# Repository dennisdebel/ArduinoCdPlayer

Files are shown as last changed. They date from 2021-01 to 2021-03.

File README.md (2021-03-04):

# Arduino CD player

Using an Arduino Pro-mini and an IDE CD-ROM drive to create a standalone CD player.
Based on the [ATAPIDUINO](http://singlevalve.web.fc2.com/Atapiduino/atapiduino.htm) project - code for this in the `original` folder.

For more details, see project on [hackaday.io](https://hackaday.io/project/176545-arduino-cd-player).

# To do
* Add opamp buffer after DAC to protect the output (from accidental plugging in other outputs).

# Supported IDE CD-ROM drives
Sources from [ATAPIDUINO](http://singlevalve.web.fc2.com/Atapiduino/atapiduino.htm) and [ArduinoCdPlayer](https://hackaday.io/project/176545-arduino-cd-player) and [here](https://hackaday.io/project/24905-using-old-cd-drive-as-a-music-player):

## Testing
* AOpen CRW5224 (2003)

## Compatible drives
* AZTECH CDA66801I (1995)
* BTC F563E (2001)
* CREATIVE CD5233E (?) (Starts PLAY instead of remaining paused when NEXT/PREV is used on stopped unit)
* HITACHI CDR-8130 (1997)
* HITACHI CDR-8230 (1997)
* LG CRD-8320B (1998)
* LG CRD-8322B (1999)
* LG CRD-8521B (2001)
* LG GCE-8527B (2005)
* LITE-ON LTN-403L (2000)
* LITE-ON LTN486S (2001)
* NEC CDR 1800A (1997)
* NEC DV-5800A (2001) ("DVD-ROM READER")
* SAMSUNG SC-148C (2001)
* SONY CDU5211 (2001)
* TEAC CD-532E (2000)
* TEAC CD-540E (2001)
* Ultima Electronics CHA-50 (????)

## Non Compatible or possible defect Units
* Compaq CRC#D-8241B (1998) (erratic, defect?)
* Compaq CR-588 (1998) (erratic, defect?)
* H.L Datastorage GCR-8481B (2002) (fails init proc.)
* LG DVD-ROM Drive GDR-H30N (2007) (fails init proc.)
* Philips DVDROM DROM6116/34 (2004) (Only reads TOC sometimes)
* Toshiba XM-6402B (1999) (fails init proc.)

# References
* https://hackaday.io/project/176545-arduino-cd-player
* https://hackaday.io/project/24905-using-old-cd-drive-as-a-music-player
* http://singlevalve.web.fc2.com/Atapiduino/atapiduino.htm 
* https://github.com/lmiori92/AtapiduinoSingleChip
* productized version of similar idea: [CD-ROM DVD-ROM IDE ROM Audio Player controller DIY kit ROM to Turntable](https://www.ebay.co.uk/itm/CD-ROM-DVD-ROM-IDE-ROM-Audio-Player-controller-DIY-kit-ROM-to-Turntable/324207457799)

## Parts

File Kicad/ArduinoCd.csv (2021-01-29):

Id | Designator | Package | Quantity | Designation | Supplier and ref
1 | REF**,REF**,REF**,REF** | MountingHole_3.2mm_M3 | 4 | MountingHole_3.2mm_M3
2 | U1,U2 | TSSOP-24_4.4x7.8mm_P0.65mm | 2 | PCA9555PW
3 | A1 | Arduino_ProMini | 1 | Arduino_ProMini
4 | C1,C2,C5,C7,C10,C12,C13,C15,C19,C21,C22,C25,C26 | C_0805_2012Metric_Pad1.15x1.40mm_HandSolder | 13 | 0.1uF
5 | C3,C4 | C_0805_2012Metric_Pad1.15x1.40mm_HandSolder | 2 | 15pF
6 | C6,C8,C18 | C_0805_2012Metric_Pad1.15x1.40mm_HandSolder | 3 | 4.7uF
7 | C9,C11,C14,C24 | C_0805_2012Metric_Pad1.15x1.40mm_HandSolder | 4 | 10uF
8 | C16,C17 | C_0805_2012Metric_Pad1.15x1.40mm_HandSolder | 2 | 2.2uF
9 | C20,C23 | C_0805_2012Metric_Pad1.15x1.40mm_HandSolder | 2 | 2.2nF
10 | D1 | LED_D3.0mm | 1 | LED
11 | D2 | D_SMB_Handsoldering | 1 | D_Small
12 | J1,J3,J5,J6,J11,J12,J13,J14 | PinHeader_1x02_P2.54mm_Vertical | 8 | Conn_01x02
13 | J2 | PinHeader_1x02_P2.54mm_Vertical | 1 | A4-A5
14 | J4 | FCR684204T | 1 | fcr684204t
15 | J7 | PinHeader_1x03_P2.54mm_Vertical | 1 | IR SENSE
16 | J8 | PinHeader_1x02_P2.54mm_Vertical | 1 | S/PDIF-IN0
17 | J9 | PinHeader_1x02_P2.54mm_Vertical | 1 | S/PDIF-IN1
18 | J10 | PinHeader_1x04_P2.54mm_Vertical | 1 | OLED
19 | J15 | PinHeader_2x20_P2.54mm_Vertical | 1 | IDE
20 | J16 | PinHeader_1x02_P2.54mm_Vertical | 1 | 12v-IN
21 | J17 | PinHeader_1x04_P2.54mm_Vertical | 1 | LineOut
22 | Q1,Q2,Q3,Q4 | SOT-23_Handsoldering | 4 | 2N7002
23 | R1 | R_0805_2012Metric_Pad1.15x1.40mm_HandSolder | 1 | 2k
24 | R2,R5,R6,R7,R8,R9,R10,R11,R12,R13,R14,R15,R16 | R_0805_2012Metric_Pad1.15x1.40mm_HandSolder | 13 | 10k
25 | R3,R4 | R_0805_2012Metric_Pad1.15x1.40mm_HandSolder | 2 | 75R
26 | R17 | R_0805_2012Metric_Pad1.15x1.40mm_HandSolder | 1 | 200k
27 | R18,R19,R20,R21,R22 | R_0805_2012Metric_Pad1.15x1.40mm_HandSolder | 5 | 100R
28 | R23 | R_0805_2012Metric_Pad1.15x1.40mm_HandSolder | 1 | 33.2k
29 | R24 | R_0805_2012Metric_Pad1.15x1.40mm_HandSolder | 1 | 499R
30 | R25 | R_0805_2012Metric_Pad1.15x1.40mm_HandSolder | 1 | 7.25k
31 | R26,R27 | R_0805_2012Metric_Pad1.15x1.40mm_HandSolder | 2 | 470R
32 | R28 | R_0805_2012Metric_Pad1.15x1.40mm_HandSolder | 1 | 49.9k
33 | R29 | R_0805_2012Metric_Pad1.15x1.40mm_HandSolder | 1 | 2.75k
34 | R30 | R_0805_2012Metric_Pad1.15x1.40mm_HandSolder | 1 | 453k
35 | SW1 | SW_SPST_B3S-1000 | 1 | Stop
36 | SW2 | SW_SPST_B3S-1000 | 1 | Play
37 | SW3 | SW_SPST_B3S-1000 | 1 | Pause
38 | SW4 | SW_SPST_B3S-1000 | 1 | PrevTrack
39 | SW5 | SW_SPST_B3S-1000 | 1 | NextTrack
40 | SW6 | SW_SPST_B3S-1000 | 1 | FastForward
41 | SW7 | SW_SPST_B3S-1000 | 1 | Rewind
42 | SW8 | SW_SPST_B3S-1000 | 1 | Eject
43 | TP1 | TestPoint_Pad_1.0x1.0mm | 1 | 3v3
44 | TP2 | TestPoint_Pad_1.0x1.0mm | 1 | MUTE
45 | TP3 | TestPoint_Pad_1.0x1.0mm | 1 | AVDD
46 | TP4 | TestPoint_Pad_1.0x1.0mm | 1 | 5v
47 | U3 | SSOP-28_5.3x10.2mm_P0.65mm | 1 | WM8805
48 | U4 | SOT-223-3_TabPin2 | 1 | AMS1117-3.3
49 | U5 | TSSOP-20_4.4x6.5mm_P0.65mm | 1 | PCM5102
50 | U6 | MSOP-10_3x3mm_P0.5mm | 1 | LT3042
51 | U7 | SOT-223-3_TabPin2 | 1 | AMS1117-5.0
52 | Y1 | Crystal_SMD_HC49-SD | 1 | 12MHz

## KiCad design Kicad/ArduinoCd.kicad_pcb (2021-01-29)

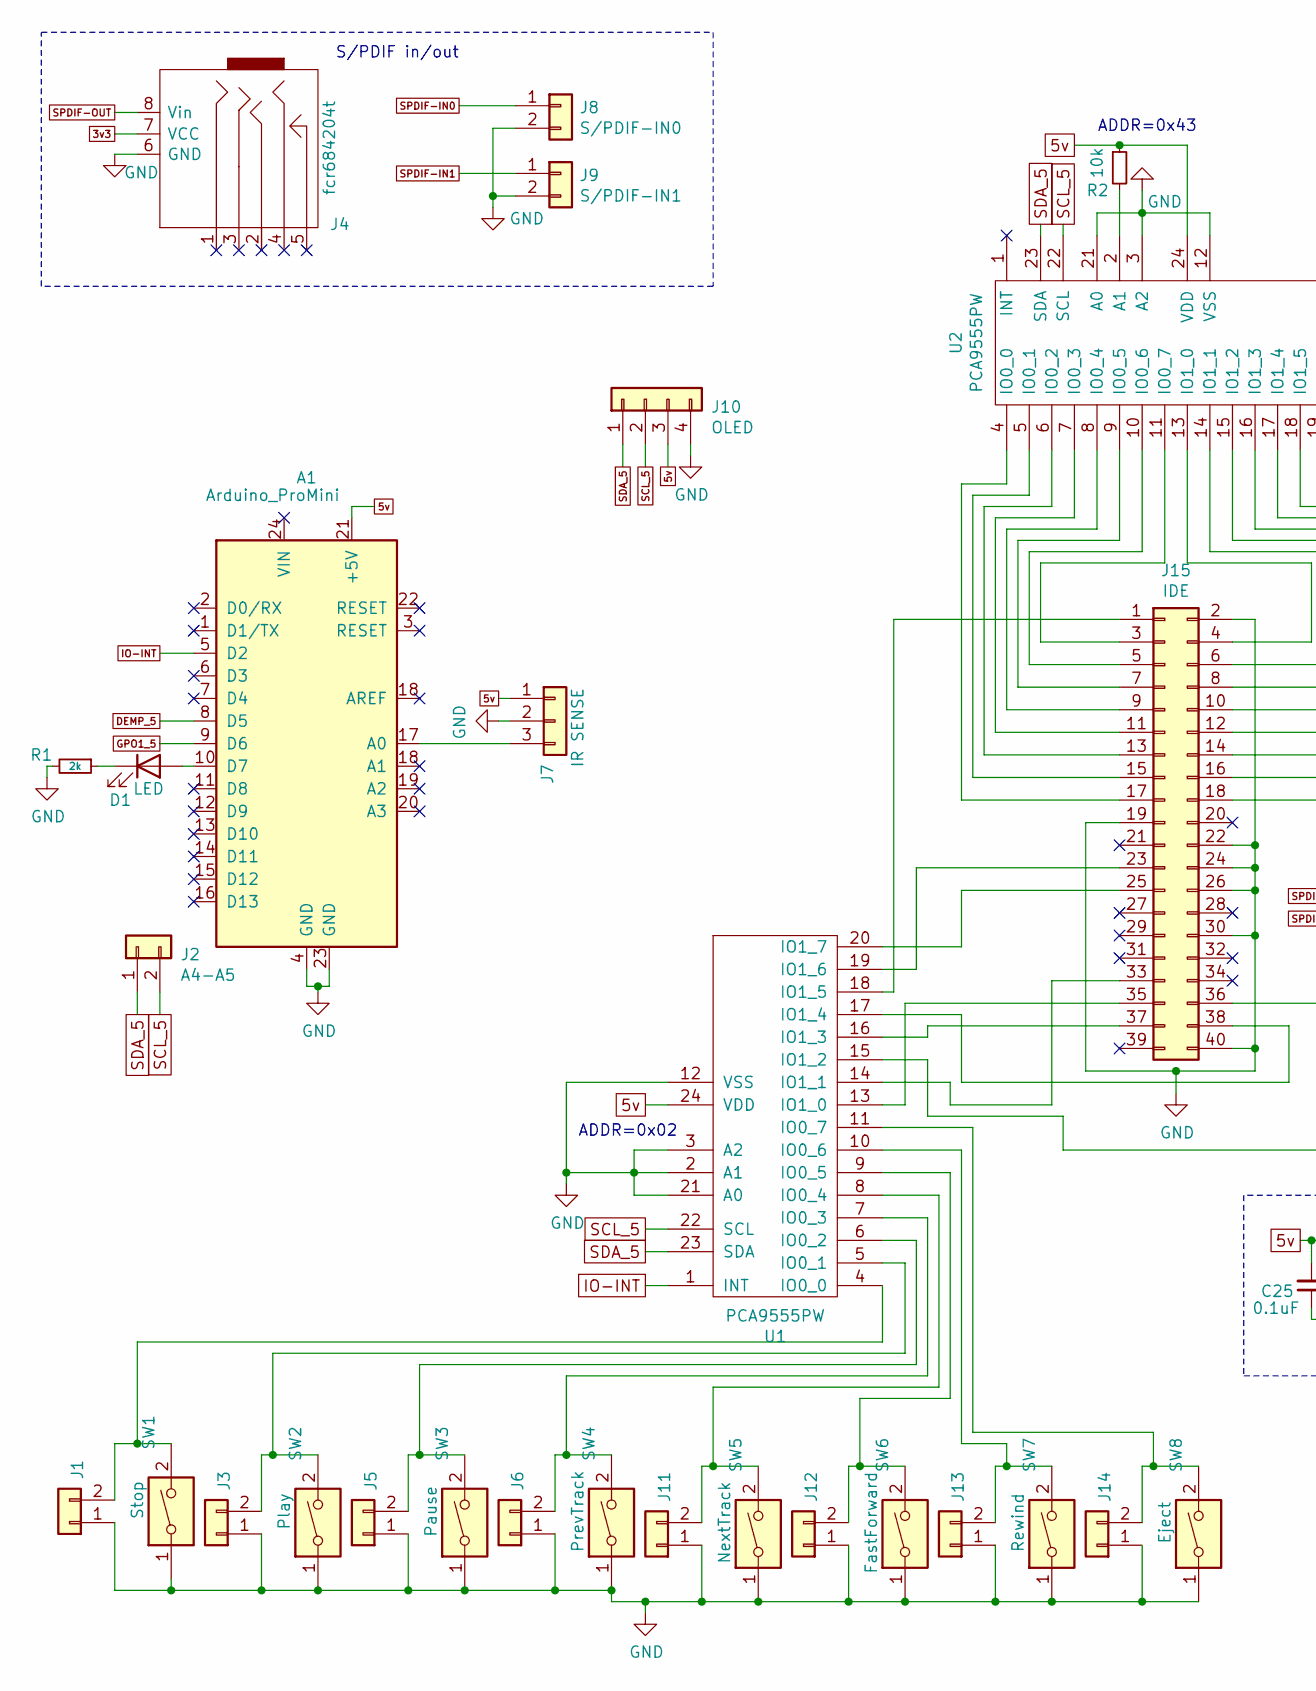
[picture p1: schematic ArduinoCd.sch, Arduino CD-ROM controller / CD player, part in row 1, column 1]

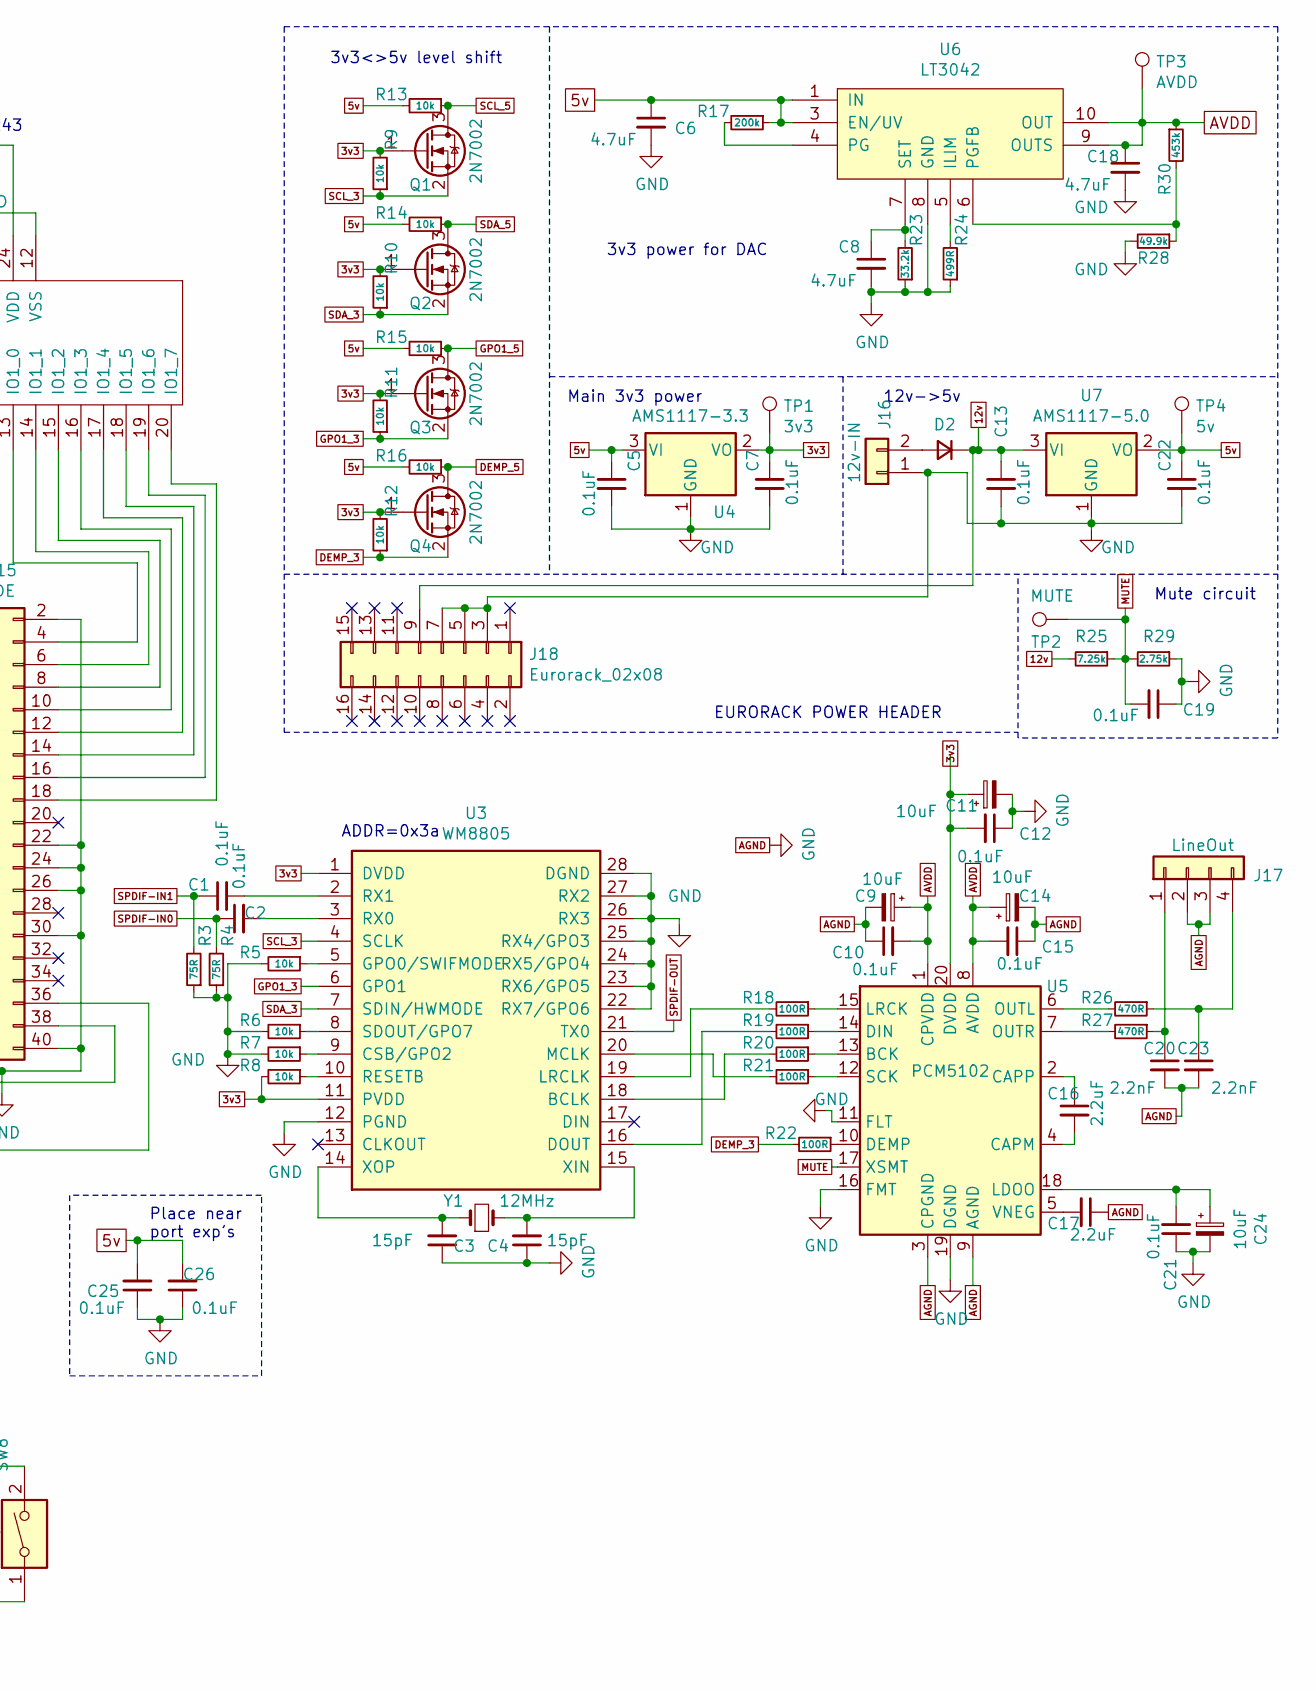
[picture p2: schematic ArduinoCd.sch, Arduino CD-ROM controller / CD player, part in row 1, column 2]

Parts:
A1: Arduino_ProMini
C1, C2, C5, C7, C10, C12, C13, C15, C19, C21, C22, C25, C26: 0.1uF; C_0805_2012Metric_Pad1.15x1.40mm_HandSolder
C3, C4: 15pF; C_0805_2012Metric_Pad1.15x1.40mm_HandSolder
C6, C8, C18: 4.7uF; C_0805_2012Metric_Pad1.15x1.40mm_HandSolder
C9, C11, C14, C24: 10uF; C_0805_2012Metric_Pad1.15x1.40mm_HandSolder
C16, C17: 2.2uF; C_0805_2012Metric_Pad1.15x1.40mm_HandSolder
C20, C23: 2.2nF; C_0805_2012Metric_Pad1.15x1.40mm_HandSolder
D1: LED; LED_D3.0mm
D2: D_Small; D_SMB_Handsoldering
J1, J3, J5, J6, J11, J12, J13, J14: Conn_01x02; PinHeader_1x02_P2.54mm_Vertical
J2: A4-A5; PinHeader_1x02_P2.54mm_Vertical
J4: fcr684204t; FCR684204T
J7: IR SENSE; PinHeader_1x03_P2.54mm_Vertical
J8: S/PDIF-IN0; PinHeader_1x02_P2.54mm_Vertical
J9: S/PDIF-IN1; PinHeader_1x02_P2.54mm_Vertical
J10: OLED; PinHeader_1x04_P2.54mm_Vertical
J15: IDE; PinHeader_2x20_P2.54mm_Vertical
J16: 12v-IN; PinHeader_1x02_P2.54mm_Vertical
J17: LineOut; PinHeader_1x04_P2.54mm_Vertical
J18: Eurorack_02x08; PinHeader_2x08_P2.54mm_Vertical
Q1, Q2, Q3, Q4: 2N7002; SOT-23_Handsoldering
R1: 2k; R_0805_2012Metric_Pad1.15x1.40mm_HandSolder
R2, R5, R6, R7, R8, R9, R10, R11, R12, R13, R14, R15, R16: 10k; R_0805_2012Metric_Pad1.15x1.40mm_HandSolder
R3, R4: 75R; R_0805_2012Metric_Pad1.15x1.40mm_HandSolder
R17: 200k; R_0805_2012Metric_Pad1.15x1.40mm_HandSolder
R18, R19, R20, R21, R22: 100R; R_0805_2012Metric_Pad1.15x1.40mm_HandSolder
R23: 33.2k; R_0805_2012Metric_Pad1.15x1.40mm_HandSolder
R24: 499R; R_0805_2012Metric_Pad1.15x1.40mm_HandSolder
R25: 7.25k; R_0805_2012Metric_Pad1.15x1.40mm_HandSolder
R26, R27: 470R; R_0805_2012Metric_Pad1.15x1.40mm_HandSolder
R28: 49.9k; R_0805_2012Metric_Pad1.15x1.40mm_HandSolder
R29: 2.75k; R_0805_2012Metric_Pad1.15x1.40mm_HandSolder
R30: 453k; R_0805_2012Metric_Pad1.15x1.40mm_HandSolder
SW1: Stop; SW_SPST_B3S-1000
SW2: Play; SW_SPST_B3S-1000
SW3: Pause; SW_SPST_B3S-1000
SW4: PrevTrack; SW_SPST_B3S-1000
SW5: NextTrack; SW_SPST_B3S-1000
SW6: FastForward; SW_SPST_B3S-1000
SW7: Rewind; SW_SPST_B3S-1000
SW8: Eject; SW_SPST_B3S-1000
TP1: 3v3; TestPoint_Pad_1.0x1.0mm
TP2: MUTE; TestPoint_Pad_1.0x1.0mm
TP3: AVDD; TestPoint_Pad_1.0x1.0mm
TP4: 5v; TestPoint_Pad_1.0x1.0mm
U1, U2: PCA9555PW; TSSOP-24_4.4x7.8mm_P0.65mm
U3: WM8805; SSOP-28_5.3x10.2mm_P0.65mm
U4: AMS1117-3.3; SOT-223-3_TabPin2
U5: PCM5102; TSSOP-20_4.4x6.5mm_P0.65mm
U6: LT3042; MSOP-10_3x3mm_P0.5mm
U7: AMS1117-5.0; SOT-223-3_TabPin2
Y1: 12MHz; Crystal_SMD_HC49-SD

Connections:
3v3: C7.1, C11.1, C12.2, J4.7 (VCC), Q1.1 (G), Q2.1 (G), Q3.1 (G), Q4.1 (G), R8.2, R9.2, R10.2, R11.2, R12.2, TP1.1, U3.1 (DVDD), U3.11 (PVDD), U4.2 (VO), U5.20 (DVDD)
5v: A1.21 (+5V), C5.1, C6.1, C22.1, C25.2, C26.2, J7.1, J10.3, R2.1, R13.2, R14.2, R15.2, R16.2, R17.1, TP4.1, U1.24 (VDD), U2.24 (VDD), U4.3 (VI), U6.1 (IN), U6.2 (IN), U6.3 (EN/UV), U7.2 (VO)
12v: C13.1, D2.1 (K), J18.9, R25.2, U7.3 (VI)
AGND: A1.4 (GND), A1.23 (GND), C3.1, C4.1, C5.2, C6.2, C7.2, C8.2, C9.2, C10.1, C11.2, C12.1, C13.2, C14.2, C15.1, C17.1, C18.2, C19.1, C20.2, C21.1, C22.2, C23.2, C24.2, C25.1, C26.1, J1.1, J3.1, J4.6 (GND), J5.1, J6.1, J7.2, J8.2, J9.2, J10.4, J11.1, J12.1, J13.1, J14.1, J15.2, J15.19, J15.22, J15.24, J15.26, J15.30, J15.40, J16.1, J17.2, J17.3, J18.3, J18.5, J18.7, R1.2, R3.1, R4.1, R5.2, R6.2, R7.2, R23.1, R24.1, R28.2, R29.1, SW1.1, SW2.1, SW3.1, SW4.1, SW5.1, SW6.1, SW7.1, SW8.1, U1.2 (A1), U1.3 (A2), U1.12 (VSS), U1.21 (A0), U2.3 (A2), U2.12 (VSS), U2.21 (A0), U3.12 (PGND), U3.22 (RX7/GPO6), U3.23 (RX6/GPO5), U3.24 (RX5/GPO4), U3.25 (RX4/GPO3), U3.26 (RX3), U3.27 (RX2), U3.28 (DGND), U4.1 (GND), U5.3 (CPGND), U5.9 (AGND), U5.11 (FLT), U5.16 (FMT), U5.19 (DGND), U6.8 (GND), U7.1 (GND)
AVDD: C9.1, C10.2, C14.1, C15.2, C18.1, R30.1, TP3.1, U5.1 (CPVDD), U5.8 (AVDD), U6.9 (OUTS), U6.10 (OUT)
DEMP_3: Q4.2 (S), R12.1, R22.2
DEMP_5: A1.8 (D5), Q4.3 (D), R16.1
GPO1_3: Q3.2 (S), R11.1, U3.6 (GPO1)
GPO1_5: A1.9 (D6), Q3.3 (D), R15.1
IO-INT: A1.5 (D2), U1.1 (INT)
MUTE: C19.2, R25.1, R29.2, TP2.1, U5.17 (XSMT)
unnamed: A1.10 (D7), D1.2 (A)
unnamed: A1.17 (A0), J7.3
unnamed: C1.2, U3.2 (RX1)
unnamed: C2.2, U3.3 (RX0)
unnamed: C3.2, U3.14 (XOP), Y1.1
unnamed: C4.2, U3.15 (XIN), Y1.2
unnamed: C8.1, R23.2, U6.7 (SET)
unnamed: C16.1, U5.2 (CAPP)
unnamed: C16.2, U5.4 (CAPM)
unnamed: C17.2, U5.5 (VNEG)
unnamed: C20.1, J17.1, R27.1
unnamed: C21.2, C24.1, U5.18 (LDOO)
unnamed: C23.1, J17.4, R26.1
unnamed: D1.1 (K), R1.1
unnamed: D2.2 (A), J16.2
unnamed: J1.2, SW1.2, U1.4 (IO0_0)
unnamed: J3.2, SW2.2, U1.5 (IO0_1)
unnamed: J5.2, SW3.2, U1.6 (IO0_2)
unnamed: J6.2, SW4.2, U1.7 (IO0_3)
unnamed: J11.2, SW5.2, U1.8 (IO0_4)
unnamed: J12.2, SW6.2, U1.9 (IO0_5)
unnamed: J13.2, SW7.2, U1.10 (IO0_6)
unnamed: J14.2, SW8.2, U1.11 (IO0_7)
unnamed: J15.1, U1.18 (IO1_5)
unnamed: J15.3, U2.11 (IO0_7)
unnamed: J15.4, U2.13 (IO1_0)
unnamed: J15.5, U2.10 (IO0_6)
unnamed: J15.6, U2.14 (IO1_1)
unnamed: J15.7, U2.9 (IO0_5)
unnamed: J15.8, U2.15 (IO1_2)
unnamed: J15.9, U2.8 (IO0_4)
unnamed: J15.10, U2.16 (IO1_3)
unnamed: J15.11, U2.7 (IO0_3)
unnamed: J15.12, U2.17 (IO1_4)
unnamed: J15.13, U2.6 (IO0_2)
unnamed: J15.14, U2.18 (IO1_5)
unnamed: J15.15, U2.5 (IO0_1)
unnamed: J15.16, U2.19 (IO1_6)
unnamed: J15.17, U2.4 (IO0_0)
unnamed: J15.18, U2.20 (IO1_7)
unnamed: J15.23, U1.19 (IO1_6)
unnamed: J15.25, U1.20 (IO1_7)
unnamed: J15.33, U1.14 (IO1_1)
unnamed: J15.35, U1.13 (IO1_0)
unnamed: J15.36, U1.15 (IO1_2)
unnamed: J15.37, U1.16 (IO1_3)
unnamed: J15.38, U1.17 (IO1_4)
unnamed: R2.2, U2.2 (A1)
unnamed: R5.1, U3.5 (GPO0/SWIFMODE)
unnamed: R6.1, U3.8 (SDOUT/GPO7)
unnamed: R7.1, U3.9 (CSB/GPO2)
unnamed: R8.1, U3.10 (RESETB)
unnamed: R17.2, U6.4 (PG)
unnamed: R18.1, U5.15 (LRCK)
unnamed: R18.2, U3.19 (LRCLK)
unnamed: R19.1, U5.14 (DIN)
unnamed: R19.2, U3.16 (DOUT)
unnamed: R20.1, U5.13 (BCK)
unnamed: R20.2, U3.18 (BCLK)
unnamed: R21.1, U5.12 (SCK)
unnamed: R21.2, U3.20 (MCLK)
unnamed: R22.1, U5.10 (DEMP)
unnamed: R24.2, U6.5 (ILIM)
unnamed: R26.2, U5.6 (OUTL)
unnamed: R27.2, U5.7 (OUTR)
unnamed: R28.1, R30.2, U6.6 (PGFB)
SCL_3: Q1.2 (S), R9.1, U3.4 (SCLK)
SCL_5: J2.2, J10.2, Q1.3 (D), R13.1, U1.22 (SCL), U2.22 (SCL)
SDA_3: Q2.2 (S), R10.1, U3.7 (SDIN/HWMODE)
SDA_5: J2.1, J10.1, Q2.3 (D), R14.1, U1.23 (SDA), U2.23 (SDA)
SPDIF-IN0: C2.1, J8.1, R4.2
SPDIF-IN1: C1.1, J9.1, R3.2
SPDIF-OUT: J4.8 (Vin), U3.21 (TX0)

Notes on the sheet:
ADDR=0x02
ADDR=0x43
3v3 power for DAC
3v3<>5v level shift
ADDR=0x3a
Main 3v3 power
12v->5v
Mute circuit
Place near port exp's
EURORACK POWER HEADER
S/PDIF in/out

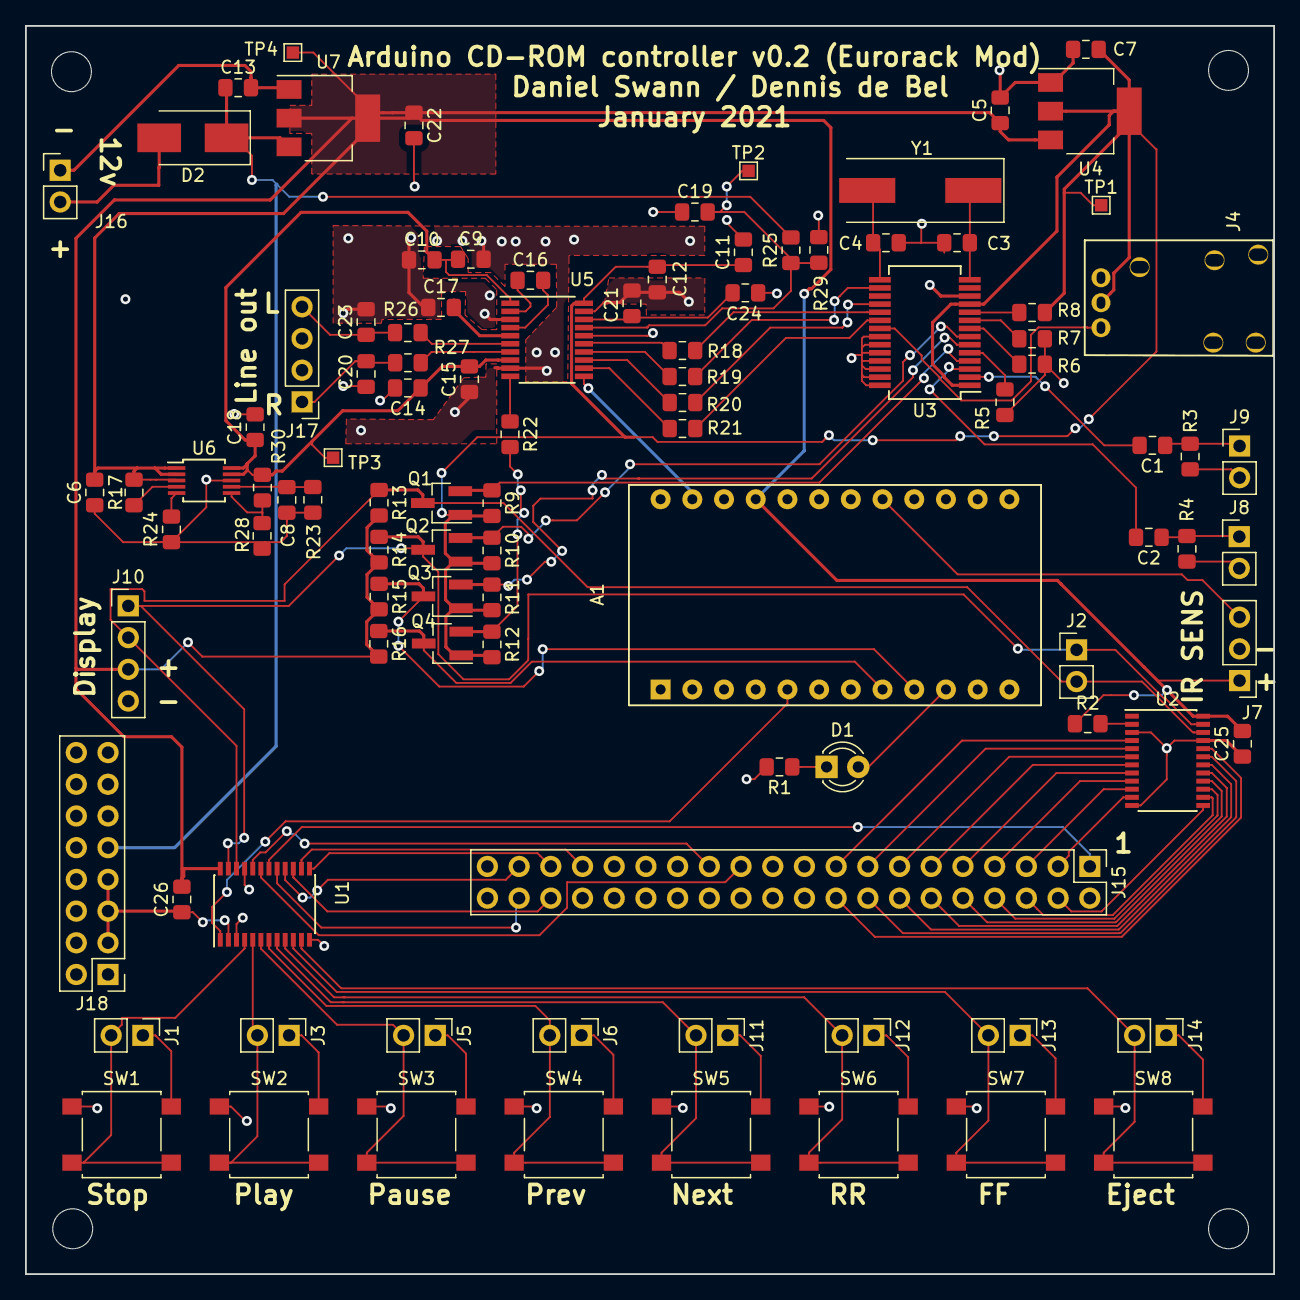
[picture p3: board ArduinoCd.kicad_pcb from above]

Board: 2 copper layers, 100.0 x 100.0 mm, 101 parts (0 on the bottom side), 84 nets.

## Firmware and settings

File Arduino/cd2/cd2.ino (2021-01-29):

/* #######################################################################

    IDE ATAPI controller and DAC for an Arduino Pro-Mini

    Copyright (C) 2020  Daniel Swann

    Heavily based on the ATAPIDUINO project:
    Copyright (C) 2012  Carlos Durandal

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
 * ####################################################################### */

#include "ide_io.h"
#include "atapi.h"
#include "controls.h"
#include "wm880x.h"
#include "display.h"

enum ScanState
{
  RR,
  FF,
  NONE
};

char get_state_char(struct atapi::sub_channel_data *sub_ch_data);
void reread_toc_on_disc_load(atapi::MediaStatus media_status);
void scan(enum ScanState scan);

#define ADDRESS_WM880x  0x3a
#define ADDRESS_DISPLAY 0x3C
#define PIN_DEEMPH 5

enum ScanState _scan_state;
ide_io *_ide   = new ide_io();
atapi  *_atapi = new atapi(_ide);
controls *_controls;
wm880x *_wm880x;
display *_display;

void setup()
{
  Wire.begin();
  Serial.begin(115200);
  Serial.println("CD Start");

  _display = new display(ADDRESS_DISPLAY);
  _display->init();

  _controls = new controls();
  _wm880x = new wm880x(ADDRESS_WM880x);
  _wm880x->init();

  pinMode(PIN_DEEMPH, OUTPUT);
  digitalWrite(PIN_DEEMPH, LOW);

  ide_io::data16 read_val;
  _scan_state = ScanState::NONE;

  _atapi->reset();

  if (_atapi->is_atapi_device())
    Serial.println("Found ATAPI Dev.");
  else
  {
    Serial.println("No ATAPI Device!");
    while(1);                          // No need to go ahead.
  }

  // Initialise task file
  Serial.println("Init task file");
  _atapi->init_task_file();
  Serial.println("Init task file done");

  // Run Self Diagnostic
  delay(3000);
  Serial.print("Self Diag: ");

  if (_atapi->run_self_diag())
  {
    Serial.println("OK");
  }
  else
  {
    Serial.println("Fail");            // Units failing this may still work fine
  }

  Serial.println("ATAPI Device:");

  // Identify Device
  struct atapi::identify_drive_details drive_details;
  _atapi->identify_drive(&drive_details);
  Serial.println(drive_details.model);

  struct atapi::sense_data sd;
  _atapi->request_sense(&sd); // Send packet 'Request Sense'

  if (sd.asc == 0x29)                                 // Req. Sense returns 'HW Reset' 
  {                                                   // (ASC=29h) at first since we had one.
    _atapi->request_sense(&sd);                       // New Req. Sense returns if media
  }                                                   // is present or not.

  do
  {
                                                  // Wait until drive is ready.
    _atapi->request_sense(&sd);                   // Some devices take some time
  } while (sd.asc == 0x04);                        // ASC=04h -> LOGICAL DRIVE NOT READY
}

// This part reads the push buttons, checks device audio status, interprets operator commands
// and displays the corresponding data depending on the status and/or the commands resulting
// from pressing the push buttons.
void loop()
{
  static unsigned long last_subchannel_read = 0;
  static unsigned long last_mode_sense = 0;
  static uint8_t current_track = 1;
  static atapi::MediaStatus media_status;

  _controls->loop();

  bool button_state;

  if (_controls->has_button_been_pressed(controls::STOP))
    _atapi->stop();

  if (_controls->has_button_been_pressed(controls::PLAY))
    _atapi->play(current_track);

  if (_controls->has_button_been_pressed(controls::PAUSE))
    _atapi->pause_toggle();

  if (_controls->has_button_been_pressed(controls::PREV))
    _atapi->prev();

  if (_controls->has_button_been_pressed(controls::NEXT))
    _atapi->next();

  if (_controls->has_button_state_changed(controls::FF, &button_state))
  {
    if (button_state)
      scan(ScanState::FF);
    else
      scan(ScanState::NONE);
  }

  if (_controls->has_button_state_changed(controls::RR, &button_state))
  {
    if (button_state)
      scan(ScanState::RR);
    else
      scan(ScanState::NONE);
  }

  if (_controls->has_button_been_pressed(controls::EJECT))
    _atapi->eject();

  struct atapi::sub_channel_data sub_ch_data;

  if (millis() - last_mode_sense > 1000)
  {
    last_mode_sense = millis();
    media_status = _atapi->mode_sense_media_status();
  }

  if (media_status == atapi::MediaStatus::DOOR_CLOSED_NO_DISC)
  {
    _display->show_message("NO DISC");
  }

  else if (media_status == atapi::MediaStatus::DOOR_OPEN)
  {
    _display->show_message("(OPEN)");
  }

  else if (millis() - last_subchannel_read > 100)
  {
    bool deemph;
    _wm880x->loop();
    deemph = _wm880x->is_deemph();
    if (deemph)
      digitalWrite(PIN_DEEMPH, HIGH);
    else
      digitalWrite(PIN_DEEMPH, LOW);

    _atapi->read_subchannel(&sub_ch_data);
    last_subchannel_read = millis();

    char state_char = get_state_char(&sub_ch_data);

    _display->show_position(sub_ch_data.track_number, sub_ch_data.relative_address.M, sub_ch_data.relative_address.S, deemph, state_char);
  }

  reread_toc_on_disc_load(media_status);
}

void scan(enum ScanState scan)
{
  switch (scan)
  {
    case ScanState::FF:
      _atapi->scan(0);
      break;

    case ScanState::RR:
      _atapi->scan(1);
      break;

    case ScanState::NONE:
      _atapi->play(0xFF);
      break;
  }

  _scan_state = scan;
}

char get_state_char(struct atapi::sub_channel_data *sub_ch_data)
{
  switch (sub_ch_data->audio_status)
  {
    case atapi::sub_channel_data::PLAY_PAUSED:
      return CHAR_PAUSE;

    case atapi::sub_channel_data::PLAY_IN_PROGRESS:
      if (_scan_state == ScanState::RR)
        return CHAR_RR;
      else if (_scan_state == ScanState::FF)
        return CHAR_FF;
      else
        return CHAR_PLAY;

    default:
      return CHAR_STOP;
  }

  return ' ';
}

void reread_toc_on_disc_load(atapi::MediaStatus media_status)
{
  static atapi::MediaStatus last_media_status = atapi::MediaStatus::DOOR_OPEN;

  if (last_media_status != media_status)
  {
    Serial.print(F("MediaStatus change "));
    Serial.print(last_media_status);
    Serial.print(F(" -> "));
    Serial.println(media_status);

    if (media_status == atapi::MediaStatus::DOOR_CLOSED_VALID_DISC || media_status == atapi::MediaStatus::DOOR_CLOSED_UNKNOWN_DISC)
    {
      Serial.println(F("(re)reading TOC"));
      _display->show_message("READING");
      _atapi->read_toc();
      Serial.print(F("First track="));
      Serial.print(_atapi->_toc.first_track);
      Serial.print(F(", last track="));
      Serial.println(_atapi->_toc.last_track);
    }

    last_media_status = media_status;
  }
}

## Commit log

2021-01-16 added tested cdrom drives
    and alphabetically sorted the list of devices
2021-01-29 renamed few folders for clarity, unzipped kicad files for Diffing purposes
    [ArduinoCd.kicad_pcb, ArduinoCd.sch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]
2021-01-29 added my version of pcb (includes power connector and bodge wire fix, but wm8805 doesnt work)
    [ArduinoCd.csv, ArduinoCd.kicad_pcb, ArduinoCd.sch]
